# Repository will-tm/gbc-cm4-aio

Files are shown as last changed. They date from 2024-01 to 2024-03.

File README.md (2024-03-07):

# GBC CM4 AIO

aio-pcb

## Description
 
This project is a drop-in replacement board that fits and Gameboy Color shell and use the same IPS display as used in GBC kits. The goal of this project is initially fun and a bit of challenge and besides that the love for the GBC form factor and the will to leverage the wide GBC modding community to create a unique and customizable handheld device.

## Features

- GBC drop-in replacement board
- CM4 core
- 1800mAh battery
- High resolution IPS display
- PCM5102a audio DAC
- Fuel gauge battery monitoring

## Requirements to Build the GBC CM4 AIO

TBD

## Code 

TBD

## To-do

- [x] Hardware familiarization - CM$ board schematics
- [x] Design v1.0 DSI test display board for LT031MDZ4000
- [x] Order v1.0 DSI test display board for LT031MDZ4000
- [x] Design v1.0 mainboard
- [x] Order v1.0 mainboard
- [x] Bring up v1.0 mainboard
- [x] Design v1.0 DSI test display board for LS029B3SX02 (evaluation)
- [x] Order v1.0 DSI test display board for LS029B3SX02
- [x] Design v1.1 mainboard
- [x] Order v1.1 mainboard
- [ ] Bring up v1.1 mainboard
- [ ] Design flex PCB including ribbon cable to accomodate the final display
- [ ] Find a way to crop DSI panel as glass lens covers some of it
- [ ] Put together a fully functional Linux image (ongoing)
- [ ] Implement an on-screen indicator for volume, brightness control via GPIOs
- [ ] Other optimizations/improvements/bug fixes
- [ ] Create prototype showcase video
- [ ] Final GitHub open source release & announcement!

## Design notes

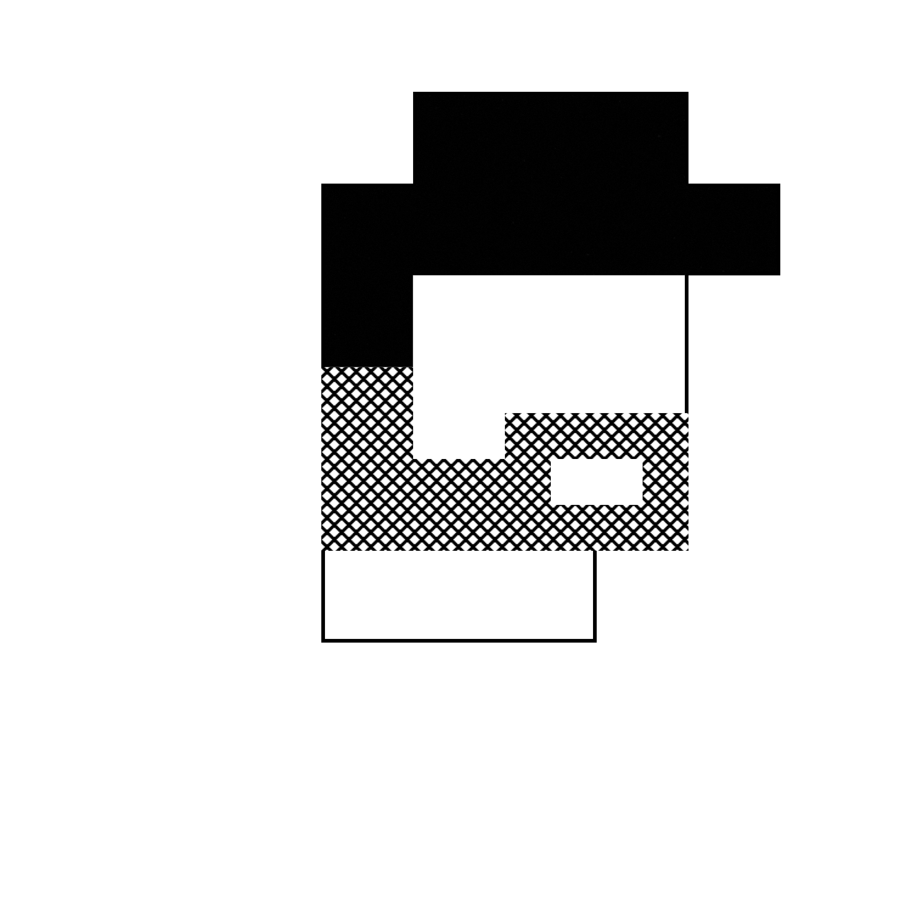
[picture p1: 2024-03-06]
PCBs/lt031mdz4000-adapter/8bitMe.png

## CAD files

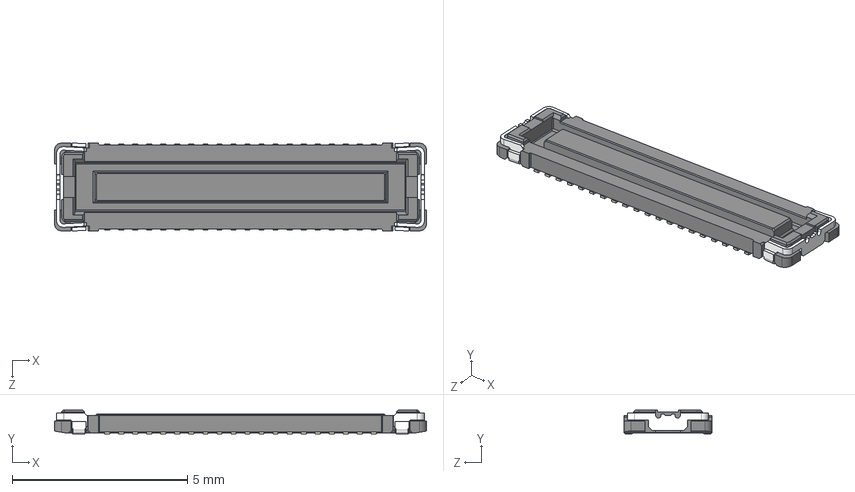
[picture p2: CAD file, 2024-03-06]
PCBs/ls029b3sx02-adapter/WP7B-S040VA1-R6000.step
10.6 x 0.68 x 2.51 mm

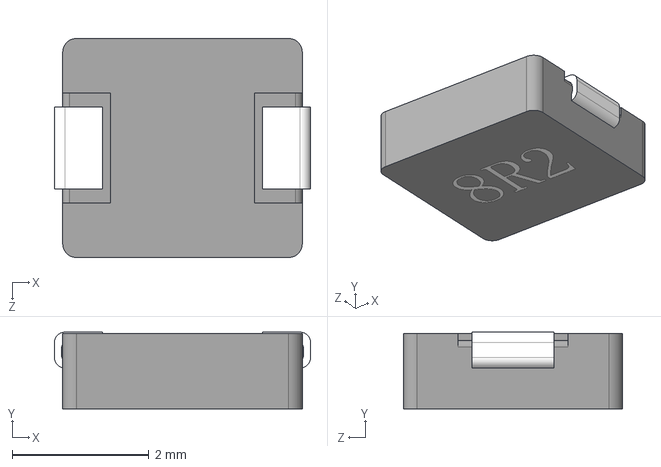
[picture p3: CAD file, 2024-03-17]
PCBs/mainboard/3d/PSMT3012.STEP
3.74 x 1.12 x 3.20 mm

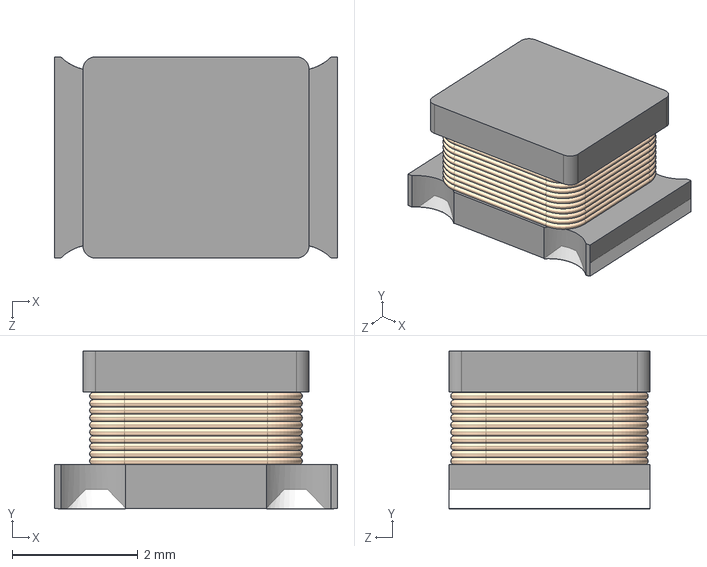
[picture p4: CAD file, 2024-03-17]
PCBs/mainboard/3d/PDS3226 Series SDM Power Inductor.STEP
4.50 x 2.51 x 3.20 mm

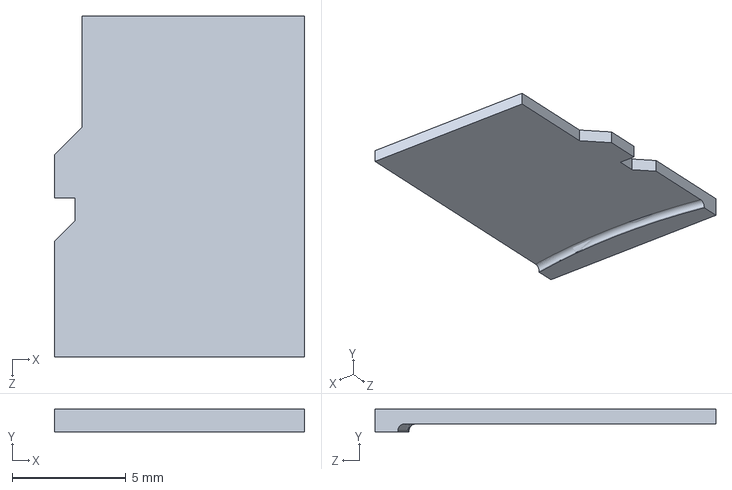
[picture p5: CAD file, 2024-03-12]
PCBs/mainboard/3d/MicroSD.STEP
11.0 x 1.00 x 15.0 mm

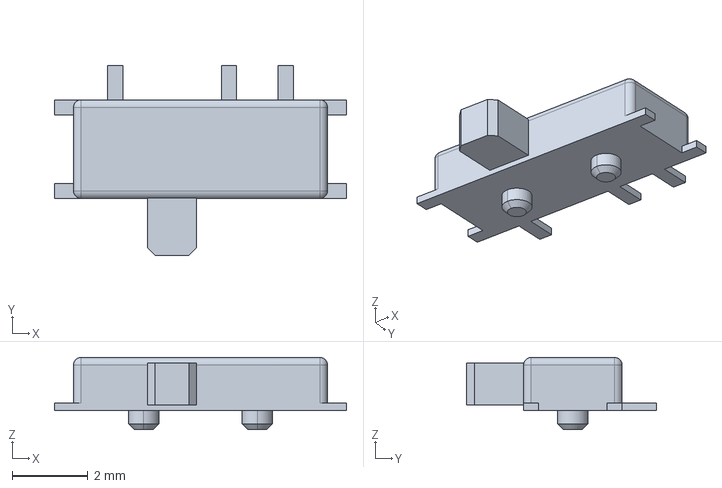
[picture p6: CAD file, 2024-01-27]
PCBs/mainboard/3d/switch_kps-1290.stp
7.70 x 5.00 x 1.90 mm

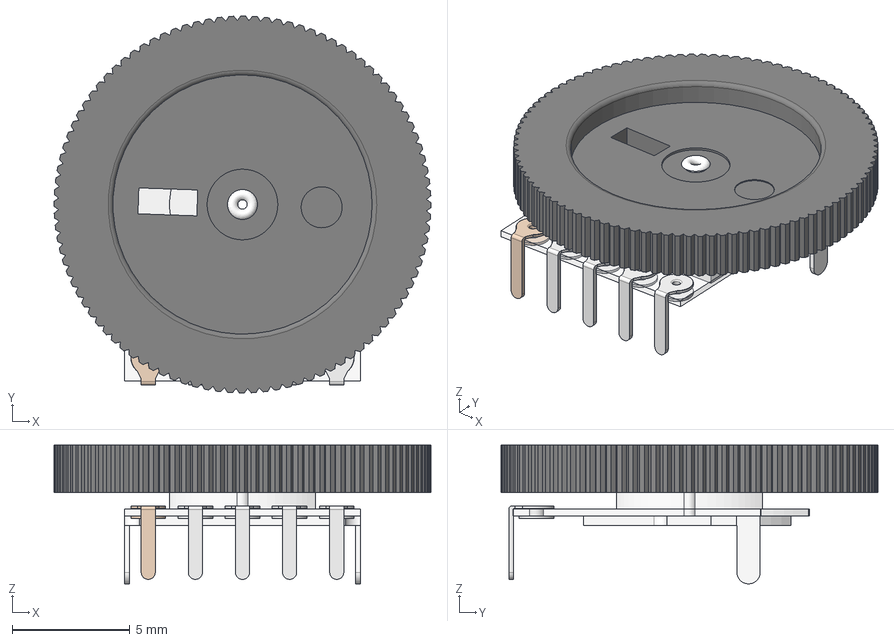
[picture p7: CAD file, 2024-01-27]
PCBs/mainboard/3d/potentiometre disk 5pin.step
16.0 x 16.0 x 5.89 mm
brochage
supp metalliq
disque
pin
pin001
pin002
pin003
pin004

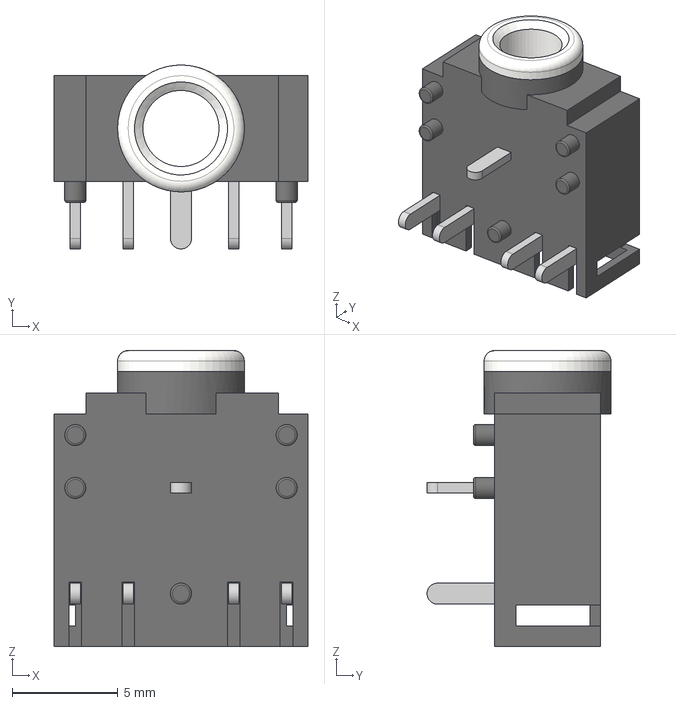
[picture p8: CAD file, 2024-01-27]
PCBs/mainboard/3d/pj-307.step
12.0 x 8.70 x 14.0 mm

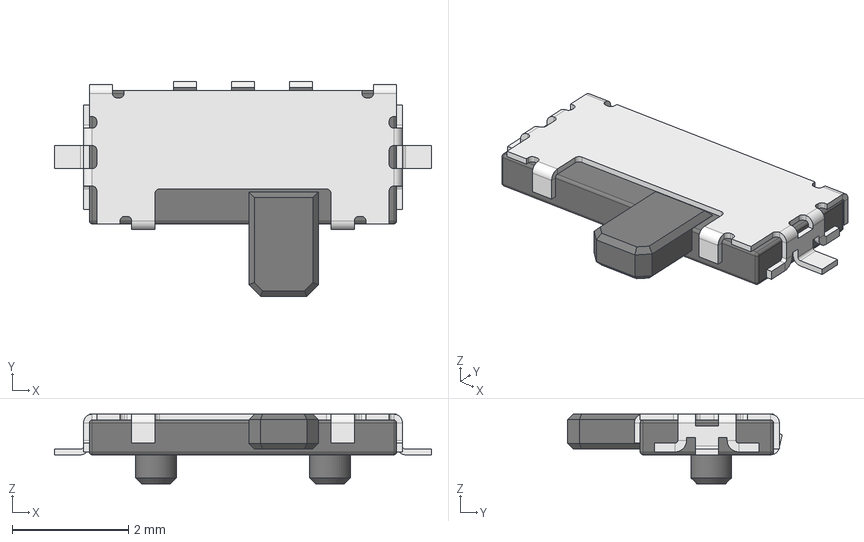
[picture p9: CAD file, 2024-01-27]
PCBs/mainboard/3d/slide_switch_MK-11C04-G013+.step
6.50 x 3.70 x 1.20 mm

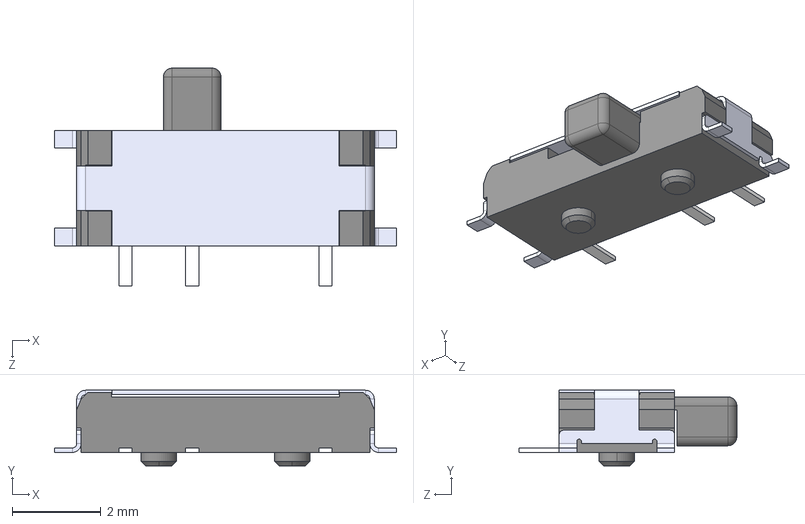
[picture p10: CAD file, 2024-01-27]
PCBs/mainboard/3d/EG1215AA.step
7.70 x 1.70 x 4.90 mm

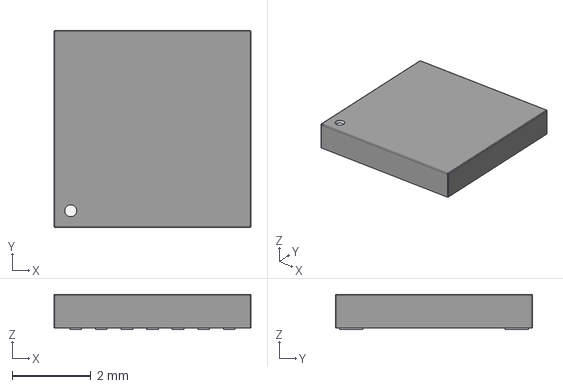
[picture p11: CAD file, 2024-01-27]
PCBs/mainboard/3d/DFN-14 5x5.step
5.00 x 5.00 x 0.9 mm

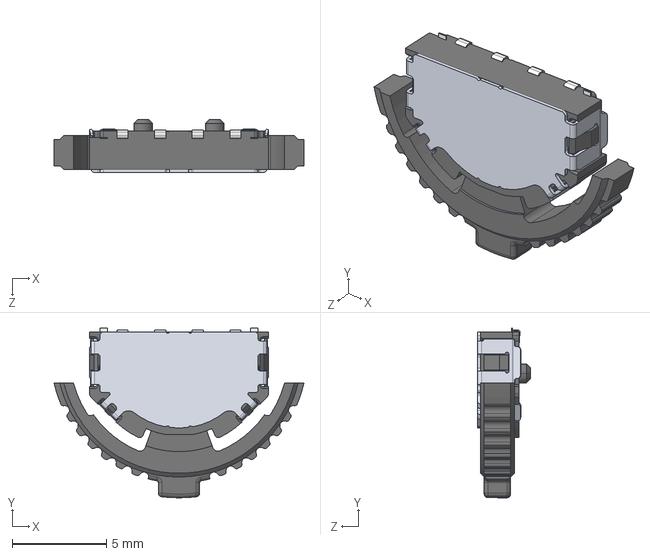
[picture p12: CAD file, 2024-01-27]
PCBs/mainboard/3d/SLLB510100.STEP
13.3 x 9.00 x 2.80 mm

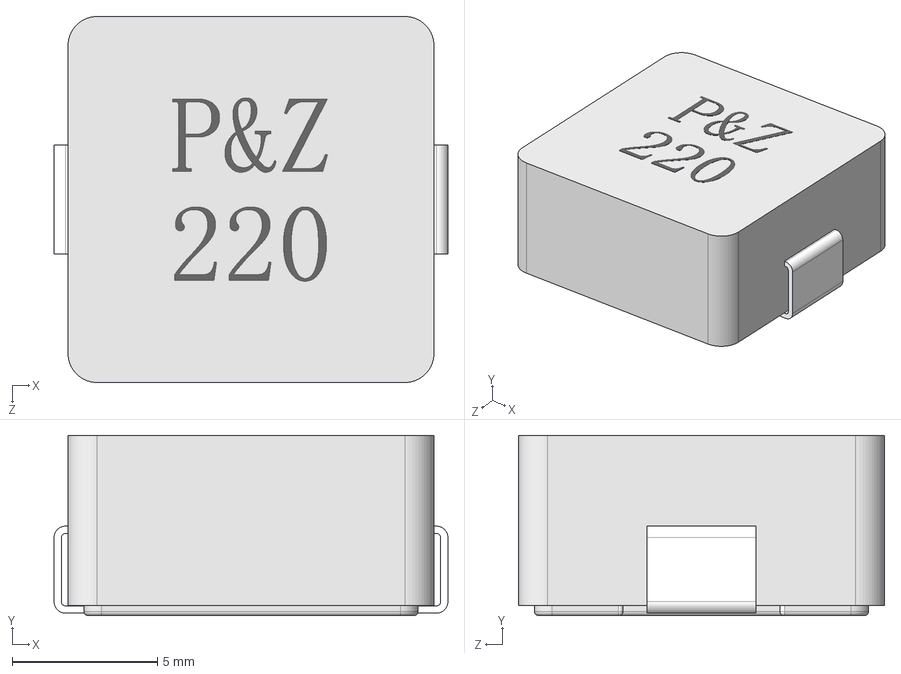
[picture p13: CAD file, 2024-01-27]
PCBs/mainboard/3d/PSM1365 Series SMD Molding inductor.STEP
13.6 x 6.21 x 12.6 mm

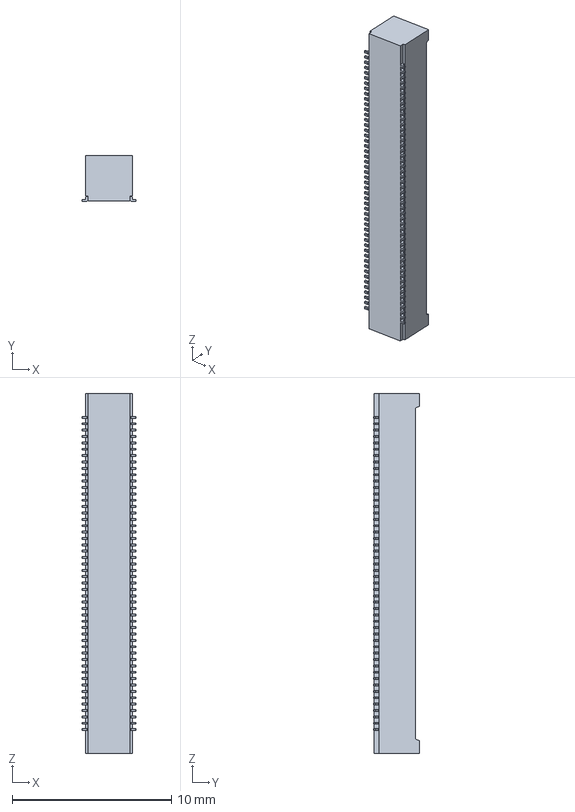
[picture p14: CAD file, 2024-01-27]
PCBs/mainboard/3d/DF40HC(3.0)-100DS-0.4V.stp
3.38 x 2.90 x 22.6 mm

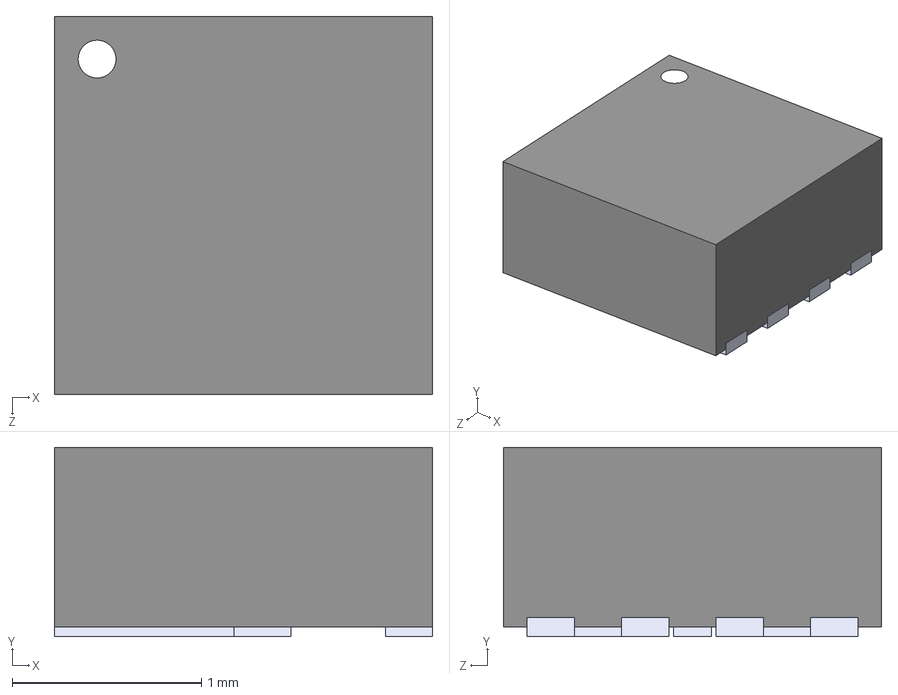
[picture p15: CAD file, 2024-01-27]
PCBs/mainboard/3d/TPS61022RWUR.step
2.00 x 1.00 x 2.00 mm

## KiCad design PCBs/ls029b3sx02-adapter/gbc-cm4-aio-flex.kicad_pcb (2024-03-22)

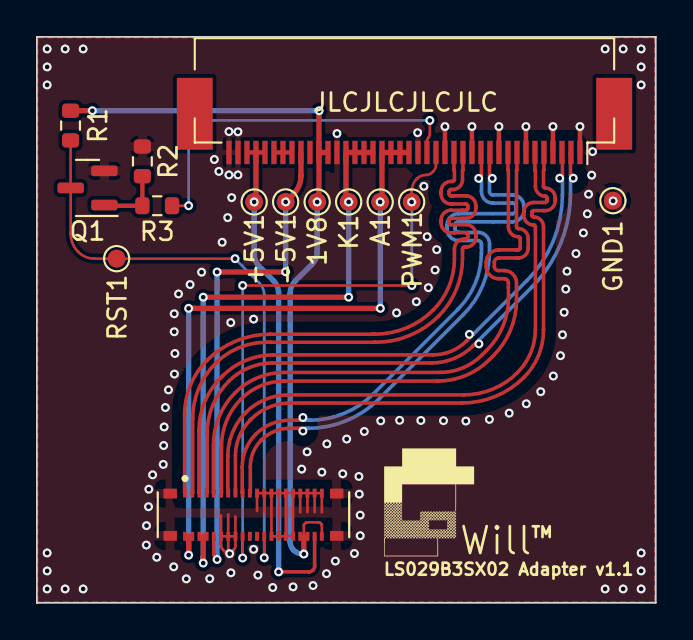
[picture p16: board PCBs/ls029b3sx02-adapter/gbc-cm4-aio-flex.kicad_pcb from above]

Board: 2 copper layers, 34.4 x 31.4 mm, 14 parts (0 on the bottom side), 20 nets.

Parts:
1V8: TestPoint; TestPoint_Pad_D1.0mm
+5V1: TestPoint; TestPoint_Pad_D1.0mm
-5V1: TestPoint; TestPoint_Pad_D1.0mm
A1: TestPoint; TestPoint_Pad_D1.0mm
GND1: TestPoint; TestPoint_Pad_D1.0mm
J2: WP7B-S040VA1-R6000; JAE_WP7B-S040VA1-R6000
J3: Conn_01x40; Hirose_FH12-40S-0.5SH_1x40-1MP_P0.50mm_Horizontal
K1: TestPoint; TestPoint_Pad_D1.0mm
PWM1: TestPoint; TestPoint_Pad_D1.0mm
Q1: BC847; SOT-23
R1, R2: 10k; R_0603_1608Metric
R3: 1k; R_0603_1608Metric
RST1: TestPoint; TestPoint_Pad_D1.0mm

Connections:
+1V8: 1V8.1, J2.21, J2.23, J2.24, J3.29, J3.30, R1.2
+5V: +5V1.1, J2.22, J3.36, J3.37, J3.38
-5V: -5V1.1, J2.36, J3.32
/CLK_N: J2.5, J3.9
/CLK_P: J2.6, J3.8
/D0_N: J2.3, J3.3
/D0_P: J2.4, J3.2
/D1_N: J2.7, J3.6
/D1_P: J2.8, J3.5
/D2_N: J2.9, J3.12
/D2_P: J2.10, J3.11
/D3_N: J2.1, J3.15
/D3_P: J2.2, J3.14
/LCD_A: A1.1, J2.39, J2.40, J3.20, J3.21, J3.22, J3.23
/LCD_K: J2.37, J2.38, J3.24, J3.25, J3.26, J3.27, K1.1
/PWM: J2.32, J3.17, PWM1.1
/RESET: J2.29, Q1.3 (C), R1.1, RST1.1
GND: GND1.1, J2.11, J2.12, J2.13, J2.14, J2.15, J2.16, J2.17, J2.18, J2.19, J2.20, J2.25, J2.26, J2.27, J2.28, J2.33, J2.34, J2.35, J2.S1 (SHIELD), J2.S2 (SHIELD), J2.S3 (SHIELD), J2.S4 (SHIELD), J3.1, J3.7, J3.10, J3.13, J3.16, J3.19, J3.28, J3.39, J3.40, Q1.2 (E), R2.1
unnamed: J3.18, R3.1
unnamed: Q1.1 (B), R2.2, R3.2

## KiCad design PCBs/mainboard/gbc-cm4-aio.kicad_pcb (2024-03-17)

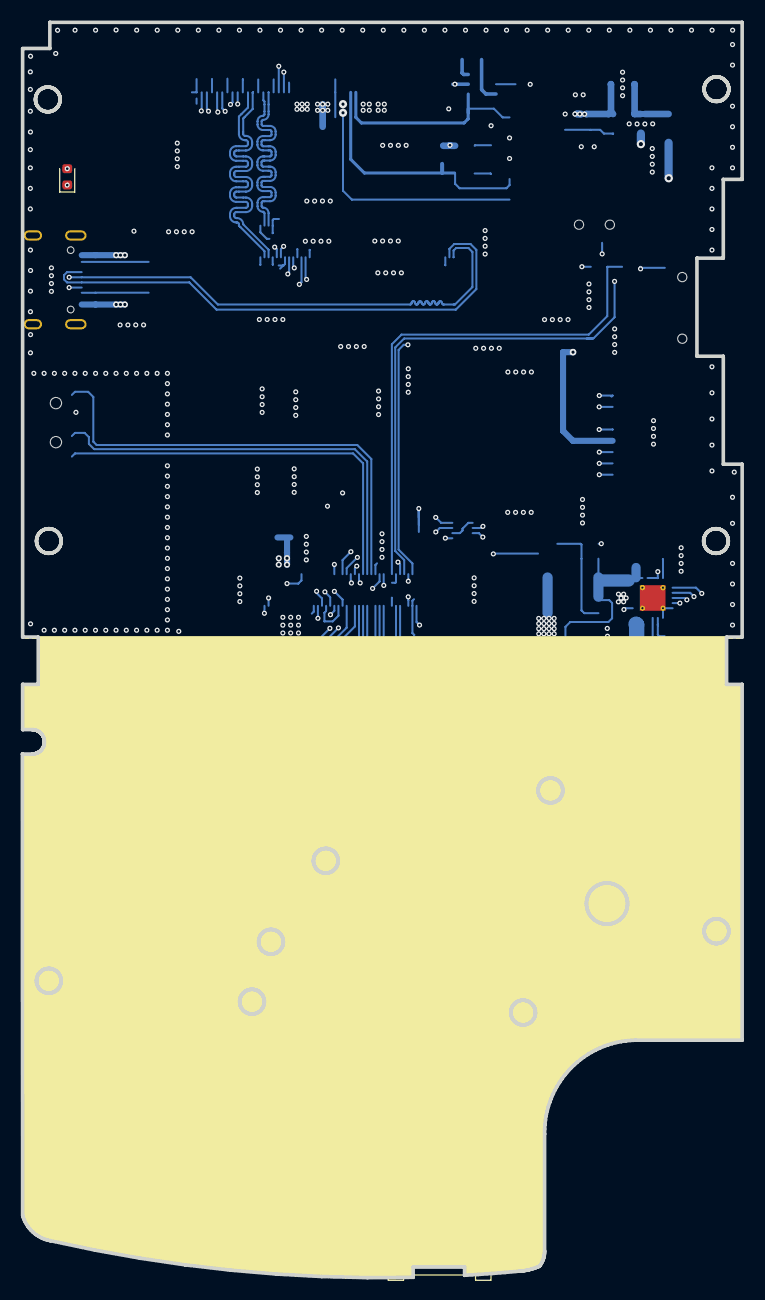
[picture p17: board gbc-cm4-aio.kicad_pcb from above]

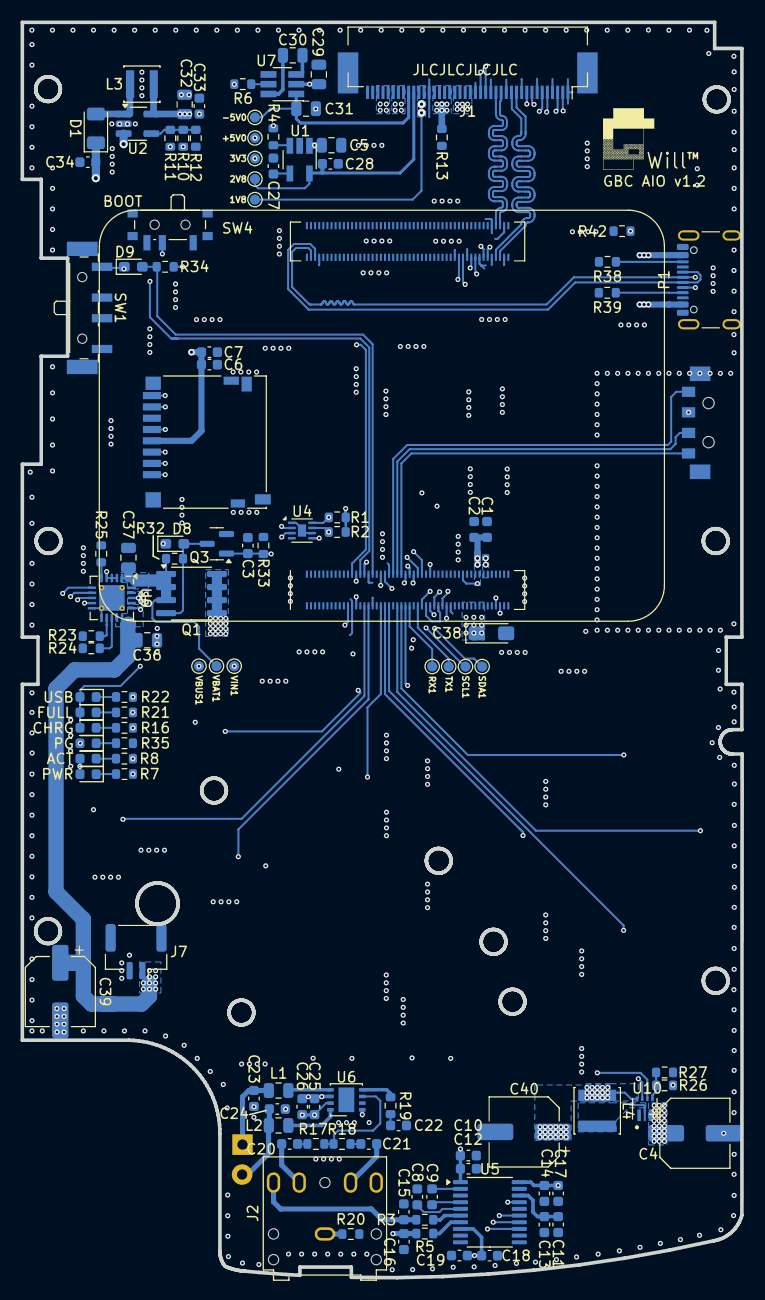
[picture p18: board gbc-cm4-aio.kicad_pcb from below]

Board: 4 copper layers, 70.1 x 122.2 mm, 118 parts (114 on the bottom side), 105 nets.

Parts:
1V8, 2V8, 3V3: TestPoint; TestPoint_Pad_D1.0mm
+5V0: TestPoint; TestPoint_Pad_D1.0mm
-5V0: TestPoint; TestPoint_Pad_D1.0mm
C1, C6, C10, C11, C14, C18, C25: 10uF; C_0603_1608Metric
C2, C7, C12, C13, C17, C19, C26: 0.1uF; C_0603_1608Metric
C3: 1nF; C_0603_1608Metric
C4, C39, C40: 865080443007; CP_Elec_6.3x5.4
C5, C29, C30, C31, C32: 10uF; C_0805_2012Metric
C8, C9: 2.2uF; C_0603_1608Metric
C15, C16: 2.2nF; C_0603_1608Metric
C20, C21, C22, C23, C24, C27: 10nF; C_0603_1608Metric
C28, C33, C34: 1uF; C_0603_1608Metric
C36, C37: 10uf; C_0805_2012Metric
C38: CP_EIA-3216-18_Kemet-A_Pad1.58x1.35mm_HandSolder
D1: D_Schottky; D_1206_3216Metric
D3, D4, D7: LED; LED_0603_1608Metric
D5: PWR; LED_0603_1608Metric
D6: ACT; LED_0603_1608Metric
D8, D9: D_Schottky; D_0603_1608Metric_Pad1.05x0.95mm_HandSolder
D10, D11: APA2107SECK; LED_0603_1608Metric
J1: Conn_01x40; Hirose_FH12-40S-0.5SH_1x40-1MP_P0.50mm_Horizontal
J2: AudioJack2_Ground_Switch; PJ307_jack
J4: DM3D-SF; microSD_HC_Hirose_DM3D-SF
J6: Conn_01x11; gbc_buttons
J7: Conn_01x02; JST_GH_SM02B-GHS-TB_1x02-1MP_P1.25mm_Horizontal
L1, L2: 300mR; C_0805_2012Metric
L3: 6.8uH; L_Changjiang_FNR3015S
L4: 1uH; L_Changjiang_FNR4020S
Module1: ComputeModule4-CM4; Raspberry-Pi-4-Compute-Module
P1: USB_C_Plug_USB2.0; USB_C_Receptacle_GCT_USB4105-xx-A_16P_TopMnt_Horizontal
Q1: AO4407C; SOIC-8_3.9x4.9mm_P1.27mm
Q3: 2N7002E; SOT-23
R1, R2: 1.8K; R_0603_1608Metric
R3, R5: 470R; R_0603_1608Metric
R4, R6, R10, R11, R12: 10k; R_0603_1608Metric
R7, R8, R16, R21, R22, R24, R35, R42: 1K; R_0603_1608Metric
R13: 2R; R_0603_1608Metric
R17, R18, R19: 150R; R_0603_1608Metric
R20: 6R8; R_0603_1608Metric
R23, R27: 100K; R_0603_1608Metric
R25, R34: 10K; R_0603_1608Metric
R26: 732K; R_0603_1608Metric
R32, R33: 1M; R_0603_1608Metric
R38, R39: 5.1K; R_0603_1608Metric
RX1: RX; TestPoint_Pad_D1.0mm
SCL1: SCL; TestPoint_Pad_D1.0mm
SDA1: SDA; TestPoint_Pad_D1.0mm
SPK+1: TestPoint; TestPoint_THTPad_2.5x2.5mm_Drill1.2mm
SPK-1: TestPoint; TestPoint_THTPad_D2.5mm_Drill1.2mm
SW1: SW_Push; SW_SP3T_PCM13
SW3: SW_Push_Dual_x2; SLLB510100
SW4: SW_SPDT; SW_SPDT_PCM12
TX1: TX; TestPoint_Pad_D1.0mm
U1: SGM2019-2.8YN5G/TR; SOT-23-5_HandSoldering
U2: FAN5333B; SOT-23-5_HandSoldering
U4: MAX17048G; TDFN-8-1EP_2x2mm_P0.5mm_EP0.8x1.2mm
U5: PCM5102; TSSOP-20_4.4x6.5mm_P0.65mm
U6: PAM8302AAY; DFN-8-1EP_3x3mm_P0.65mm_EP1.55x2.4mm
U7: SGM3204YN6G/TR; SOT-23-6_Handsoldering
U9: MCP73871-2CAI_ML; QFN-20-1EP_4x4mm_P0.5mm_EP2.5x2.5mm_ThermalVias
U10: TPS61022RWUR; CONV_TPS61022RWUR
VBAT1: VBAT; TestPoint_Pad_D1.0mm
VBUS1: VBUS; TestPoint_Pad_D1.0mm
VIN1: VIN; TestPoint_Pad_D1.0mm

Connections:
+1V8: 1V8.1, J1.29, J1.30, Module1.88 (+1.8v_(Output)), Module1.90 (+1.8v_(Output))
+2V8: 2V8.1, C28.1, J1.31, U1.5 (OUT)
+3V3: 3V3.1, C1.1, C2.1, C5.1, C6.1, C7.1, C10.1, C12.1, C14.1, C17.1, C18.1, C19.1, C32.1, C33.1, D5.2 (A), D6.2 (A), D11.2 (A), J1.33, J1.34, J1.35, J4.4 (VDD), L3.1, Module1.78 (GPIO_VREF(1.8v/3.3v_Input)), Module1.84 (+3.3v_(Output)), Module1.86 (+3.3v_(Output)), R1.1, R2.1, R4.1, R34.2, U1.1 (IN), U2.5 (VIN), U4.3 (VDD), U5.1 (CPVDD), U5.8 (AVDD), U5.17 (XSMT), U5.20 (DVDD)
+5V: +5V0.1, C4.1, C25.1, C26.1, C29.1, C38.1, D10.2 (A), J1.36, J1.37, J1.38, Module1.77 (+5v_(Input)), Module1.79 (+5v_(Input)), Module1.81 (+5v_(Input)), Module1.83 (+5v_(Input)), Module1.85 (+5v_(Input)), Module1.87 (+5v_(Input)), R6.1, R26.1, U6.1 (~SD), U6.6 (VDD), U7.2 (IN), U10.3 (VOUT)
+BATT: C36.2, C39.1, J7.1, U4.2 (CELL), U9.14 (VBAT), U9.15 (VBAT), U9.16 (VBAT_SENSE)
-5V: -5V0.1, C31.1, J1.32, U7.1 (OUT)
/ACT_LED: Module1.21 (PI_nLED_Activity), R8.2
/ALERT: Module1.30 (GPIO6), U4.5 (ALRT)
/AMP_L: C20.1, J2.TN
/AMP_R: C21.1, J2.RN
/AUDIO_L: C15.2, J2.T, R3.1
/AUDIO_R: C16.1, J2.R, R5.1
/BL_PWM: Module1.28 (GPIO13), R11.1
/BTN_A: J6.6, Module1.29 (GPIO16)
/BTN_B: J6.5, Module1.31 (GPIO12)
/BTN_BOTTOM: J6.3, Module1.41 (GPIO25)
/BTN_LEFT: J6.4, Module1.45 (GPIO24)
/BTN_RIGHT: J6.2, Module1.39 (GPIO8)
/BTN_SELECT: J6.8, Module1.54 (GPIO4)
/BTN_START: J6.7, Module1.50 (GPIO17)
/BTN_UP: J6.1, Module1.47 (GPIO23)
/BTN_X: J6.10, Module1.40 (GPIO9)
/BTN_Y: J6.9, Module1.37 (GPIO7)
/DSI1_BL_A: C34.2, D1.1 (K), J1.20, J1.21, J1.22, J1.23
/DSI1_BL_K: J1.24, J1.25, J1.26, J1.27, R13.2, U2.3 (FB)
/DSI1_CLK_N: J1.9, Module1.187 (DSI1_C_N)
/DSI1_CLK_P: J1.8, Module1.189 (DSI1_C_P)
/DSI1_D0_N: J1.3, Module1.175 (DSI1_D0_N)
/DSI1_D0_P: J1.2, Module1.177 (DSI1_D0_P)
/DSI1_D1_N: J1.6, Module1.181 (DSI1_D1_N)
/DSI1_D1_P: J1.5, Module1.183 (DSI1_D1_P)
/DSI1_D2_N: J1.12, Module1.193 (DSI1_D2_N)
/DSI1_D2_P: J1.11, Module1.195 (DSI1_D2_P)
/DSI1_D3_N: J1.15, Module1.194 (DSI1_D3_N)
/DSI1_D3_P: J1.14, Module1.196 (DSI1_D3_P)
/DSI1_PWM: J1.17, R10.1
/DSI1_RESET: J1.18, Module1.24 (GPIO26)
/IP0: P1.A5 (CC1), R39.1
/IP1: P1.B5 (CC2), R38.1
/NAV_CLICK: Module1.46 (GPIO22), SW3.T1 (C)
/NAV_DOWN: Module1.48 (GPIO27), SW3.2 (D)
/NAV_UP: Module1.44 (GPIO10), SW3.1 (C)
/PCM_CLK: Module1.49 (GPIO18), U5.13 (BCK)
/PCM_DOUT: Module1.25 (GPIO21), U5.14 (DIN)
/PCM_FS: Module1.26 (GPIO19), U5.15 (LRCK)
/PWR_LED: Module1.95 (nPI_LED_PWR), R7.2
/PWR_ON: C3.2, Module1.38 (GPIO11), Q3.1 (G), R33.2
/PWR_SW: D9.2 (A), Module1.34 (GPIO5), R34.1
/RPI_BOOT: Module1.93 (nRPIBOOT), SW4.2 (B)
/RXD0: Module1.51 (GPIO15), RX1.1
/SCL1: Module1.56 (GPIO3), R2.2, SCL1.1, U4.7 (SCL)
/SDA1: Module1.58 (GPIO2), R1.2, SDA1.1, U4.8 (SDA)
/SD_CLK: J4.5 (CLK), Module1.57 (SD_CLK)
/SD_CMD: J4.3 (CMD), Module1.62 (SD_CMD)
/SD_DAT0: J4.7 (DAT0), Module1.63 (SD_DAT0)
/SD_DAT1: J4.8 (DAT1), Module1.67 (SD_DAT1)
/SD_DAT2: J4.1 (DAT2), Module1.69 (SD_DAT2)
/SD_DAT3: J4.2 (DAT3/CD), Module1.61 (SD_DAT3)
/SW: L4.2, U10.2 (SW)
/TXD0: Module1.55 (GPIO14), TX1.1
/USB_N: Module1.103 (USB2_N), P1.A7 (D-), P1.B7 (D-)
/USB_P: Module1.105 (USB2_P), P1.A6 (D+), P1.B6 (D+)
/VBAT: C37.2, Q1.1 (S), Q1.2 (S), Q1.3 (S), R32.1, U9.1 (OUT), U9.20 (OUT), VBAT1.1
/VIN: C40.1, L4.1, Q1.5 (D), Q1.6 (D), Q1.7 (D), Q1.8 (D), U10.5 (EN), U10.7 (VIN), VIN1.1
GND: C1.2, C2.2, C3.1, C4.2, C5.2, C6.2, C7.2, C8.2, C10.2, C11.2, C12.2, C13.2, C14.2, C15.1, C16.2, C17.2, C18.2, C19.2, C22.1, C23.2, C24.1, C25.2, C26.2, C27.2, C28.2, C29.2, C31.2, C32.2, C33.2, C34.1, C36.1, C37.1, C38.2, C39.2, C40.2, J1.1, J1.4, J1.7, J1.10, J1.13, J1.16, J1.19, J1.28, J1.39, J1.40, J4.6 (VSS), J4.11 (SHIELD), J6.11, J7.2, Module1.1 (GND), Module1.2 (GND), Module1.7 (GND), Module1.8 (GND), Module1.13 (GND), Module1.14 (GND), Module1.22 (GND), Module1.23 (GND), Module1.32 (GND), Module1.33 (GND), Module1.42 (GND), Module1.43 (GND), Module1.52 (GND), Module1.53 (GND), Module1.59 (GND), Module1.60 (GND), Module1.65 (GND), Module1.66 (GND), Module1.71 (GND), Module1.74 (GND), Module1.98 (GND), Module1.107 (GND), Module1.108 (GND), Module1.113 (GND), Module1.114 (GND), Module1.119 (GND), Module1.120 (GND), Module1.125 (GND), Module1.126 (GND), Module1.131 (GND), Module1.132 (GND), Module1.137 (GND), Module1.138 (GND), Module1.144 (GND), Module1.150 (GND), Module1.155 (GND), Module1.156 (GND), Module1.161 (GND), Module1.162 (GND), Module1.167 (GND), Module1.168 (GND), Module1.173 (GND), Module1.174 (GND), Module1.179 (GND), Module1.180 (GND), Module1.185 (GND), Module1.186 (GND), Module1.191 (GND), Module1.192 (GND), Module1.197 (GND), Module1.198 (GND), P1.A1 (GND), P1.A12 (GND), P1.B1 (GND), P1.B12 (GND), P1.S1 (SHIELD), Q3.2 (S), R12.1, R13.1, R20.2, R23.2, R24.2, R25.2, R27.2, R33.1, R35.2, R38.2, R39.2, R42.2, SW1.2, SW3.C1 (D), SW4.3 (C), U1.2 (GND), U2.2 (GND), U4.1 (CTG), U4.4 (GND), U4.6 (QSTRT), U4.9 (GND), U5.3 (CPGND), U5.9 (AGND), U5.10 (DEMP), U5.11 (FLT), U5.16 (FMT), U5.19 (DGND), U6.7 (GND), U7.4 (GND), U9.10 (VSS), U9.11 (VSS), U9.21 (VSS), U10.1 (GND), U10.6 (MODE)
GNDA: J2.S, R20.1
unnamed: C20.2, R17.2
unnamed: C21.2, R18.2
unnamed: C22.2, R19.2
unnamed: C23.1, L1.1, SPK+1.1
unnamed: C24.2, L2.1, SPK-1.1
unnamed: D1.2 (A), L3.2, U2.1 (SW)
unnamed: D3.1 (K), R16.2
unnamed: D4.1 (K), R21.2
unnamed: D5.1 (K), R7.1
unnamed: D6.1 (K), R8.1
unnamed: D7.1 (K), R22.2
unnamed: D8.2 (A), Q1.4 (G), Q3.3 (D), R32.2
unnamed: D8.1 (K), D9.1 (K), SW1.1
unnamed: D10.1 (K), R35.1
unnamed: D11.1 (K), R42.1
unnamed: C27.1, U1.4 (BP)
unnamed: R4.2, U1.3 (EN)
unnamed: R10.2, R11.2, R12.2, U2.4 (SHDN)
unnamed: C9.2, U5.4 (CAPM)
unnamed: C9.1, U5.2 (CAPP)
unnamed: C11.1, C13.1, U5.18 (LDOO)
unnamed: R3.2, U5.6 (OUTL)
unnamed: R5.2, U5.7 (OUTR)
unnamed: C8.1, U5.5 (VNEG)
unnamed: R17.1, R18.1, U6.3 (IN+)
unnamed: R19.1, U6.4 (IN-)
unnamed: L1.2, U6.5 (OUT+)
unnamed: L2.2, U6.8 (OUT-)
unnamed: C30.2, U7.6 (CFLY+)
unnamed: C30.1, U7.3 (CFLY-)
unnamed: R6.2, U7.5 (EN)
unnamed: R24.1, U9.13 (PROG1)
unnamed: R23.1, U9.12 (PROG3)
unnamed: R22.1, U9.8 (STAT1/~LBO)
unnamed: R21.1, U9.7 (STAT2)
unnamed: R25.1, U9.5 (THERM)
unnamed: R16.1, U9.6 (~PG)
unnamed: R26.2, R27.1, U10.4 (FB)
VBUS: D3.2 (A), D4.2 (A), D7.2 (A), P1.A4 (VBUS), P1.A9 (VBUS), P1.B4 (VBUS), P1.B9 (VBUS), U9.2 (VPCC), U9.3 (SEL), U9.4 (PROG2), U9.9 (~TE), U9.17 (CE), U9.18 (IN), U9.19 (IN), VBUS1.1

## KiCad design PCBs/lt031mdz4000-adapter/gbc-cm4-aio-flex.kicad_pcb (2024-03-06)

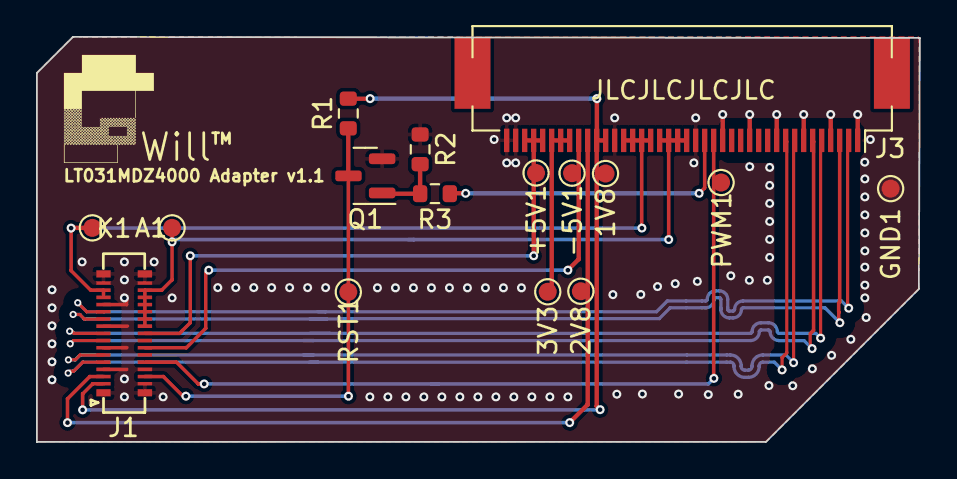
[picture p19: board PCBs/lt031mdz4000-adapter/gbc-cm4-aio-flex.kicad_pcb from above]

Board: 2 copper layers, 49.1 x 22.5 mm, 16 parts (0 on the bottom side), 18 nets.

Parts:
1V8, 2V8, 3V3: TestPoint; TestPoint_Pad_D1.0mm
+5V1: TestPoint; TestPoint_Pad_D1.0mm
-5V1: TestPoint; TestPoint_Pad_D1.0mm
A1: TestPoint; TestPoint_Pad_D1.0mm
GND1: TestPoint; TestPoint_Pad_D1.0mm
J1: Conn_02x15_Odd_Even; BM14B(0.8)-30DS-0.4V(52)
J3: Conn_01x40; Hirose_FH12-40S-0.5SH_1x40-1MP_P0.50mm_Horizontal
K1: TestPoint; TestPoint_Pad_D1.0mm
PWM1: TestPoint; TestPoint_Pad_D1.0mm
Q1: BC847; SOT-23
R1, R2: 10k; R_0603_1608Metric
R3: 1k; R_0603_1608Metric
RST1: TestPoint; TestPoint_Pad_D1.0mm

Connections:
+1V8: 1V8.1, J1.1, J3.29, J3.30, R1.2
+2V8: 2V8.1, J1.3, J3.31
+3.3V: 3V3.1, J3.33, J3.34, J3.35
+5V: +5V1.1, J1.16, J3.36, J3.37, J3.38
-5V: -5V1.1, J1.12, J3.32
/CLK_N: J1.7, J3.9
/CLK_P: J1.9, J3.8
/D0_N: J1.19, J3.3
/D0_P: J1.21, J3.2
/D1_N: J1.13, J3.6
/D1_P: J1.15, J3.5
/LCD_A: A1.1, J1.18, J1.20, J1.22, J1.24, J1.26, J1.28, J3.20, J3.21, J3.22, J3.23
/LCD_K: J1.25, J1.27, J3.24, J3.25, J3.26, J3.27, K1.1
/PWM: J1.8, J3.17, PWM1.1
/RESET: J1.4, Q1.3 (C), R1.1, RST1.1
GND: GND1.1, J1.2, J1.5, J1.6, J1.10, J1.11, J1.14, J1.17, J1.23, J1.29, J1.30, J1.MP, J3.1, J3.7, J3.10, J3.13, J3.16, J3.19, J3.28, J3.39, J3.40, Q1.2 (E), R2.1
unnamed: J3.18, R3.1
unnamed: Q1.1 (B), R2.2, R3.2

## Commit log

2024-01-27 minor tweaks
    [gbc-cm4-aio.kicad_sch]
2024-02-24 MAX17048 package fix, added front power led, minor tweaks
    [gbc-cm4-aio.kicad_sch]
2024-03-02 remove global_en, move boot to more accessible location
    [gbc-cm4-aio.kicad_pcb, gbc-cm4-aio.kicad_sch]
2024-03-02 usbc positioning improvement
    [gbc-cm4-aio.kicad_pcb]
2024-03-02 volume wheel positioning improvement
    [gbc-cm4-aio.kicad_pcb]
2024-03-02 led positioning improvement
    [gbc-cm4-aio.kicad_pcb, gbc-cm4-aio.kicad_sch]
2024-03-03 move x button to avoid potential conflict with i2s
    [gbc-cm4-aio.kicad_sch]
2024-03-03 display connector positioning improvement, display lines delay matching
2024-03-04 clean small drill sizes
    [gbc-cm4-aio.kicad_pcb]
2024-03-05 Backlight driver improvement
    [gbc-cm4-aio.kicad_pcb, gbc-cm4-aio.kicad_sch]
2024-03-05 battery connector positioning improvement
    [gbc-cm4-aio.kicad_pcb]
2024-03-05 relayout power supply and audio
    [gbc-cm4-aio.kicad_pcb]
2024-03-06 cosmetics and optimizations
    [gbc-cm4-aio.kicad_sch]
2024-03-06 added battery gauge alert
    [gbc-cm4-aio.kicad_sch]
2024-03-06 added adapter boards
    [DF40HC(3.0)-100DS-0.4V.stp, DFN-14 5x5.step, EG1215AA.step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]
2024-03-07 Remove ignored files
    [gbc-cm4-aio-flex-B_Cu.gbr, gbc-cm4-aio-flex-B_Mask.gbr, gbc-cm4-aio-flex-B_Paste.gbr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]
2024-03-12 revise sd card and lcd driver placement
    [MicroSD.STEP, gbc-cm4-aio.kicad_sch]
2024-03-12 bump version number
    [gbc-cm4-aio.kicad_pcb]
2024-03-17 move i2c bus to i2c1
    [gbc-cm4-aio.kicad_pcb, gbc-cm4-aio.kicad_sch]
2024-03-17 bring back leds to back
2024-03-17 revise inductors packages
    [PDS3226 Series SDM Power Inductor.STEP, PSMT3012.STEP, gbc-cm4-aio.kicad_sch]
2024-03-17 minor optimizations
    [gbc-cm4-aio.kicad_pcb, gbc-cm4-aio.kicad_sch]
2024-03-22 fix ls029b3sx02-adapter connector package
    [gbc-cm4-aio-flex.kicad_pcb]
2024-03-25 mainboard placement optimization
    [gbc-cm4-aio.kicad_sch]
2024-03-26 added tactile switches
    [gbc-cm4-aio.kicad_sch]
